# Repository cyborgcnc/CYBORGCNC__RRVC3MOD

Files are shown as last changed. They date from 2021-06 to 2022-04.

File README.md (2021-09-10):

# CYBORGCNC__RatRigVCORE3_MOD
Thse are modifications I recently made to the RatRig Vcore3 3D printer.  I drew a lot of inspiration from members of the Voron team, as well as other folks who have and are modifying this awesome printer.  I have also been a long time computer/gaming rig Modder, and I used some of the techniques there to make this printer simply awesome looking (my opinion). All parts were 3D printed, and the panels for all the sides etc., were cut from polycarbonate on my “homemade” CNC machine.  All of the modeling was done in Solidworks, and this would not have been possible, if it was not for the great models provided by the RatRig team!

I will be placing all the models I used to mod this printer here over time.  You can find me on the Facebook Group, so post there if you have any questions.

I would also like to thank Marcel Becker, Phil Brickwood, and Russel Brown, for their contributions in remixing some of these files for other sizes or part sizes.

If you like these mods, you can buy me a beer, or a cup of coffee!



<p align="center">
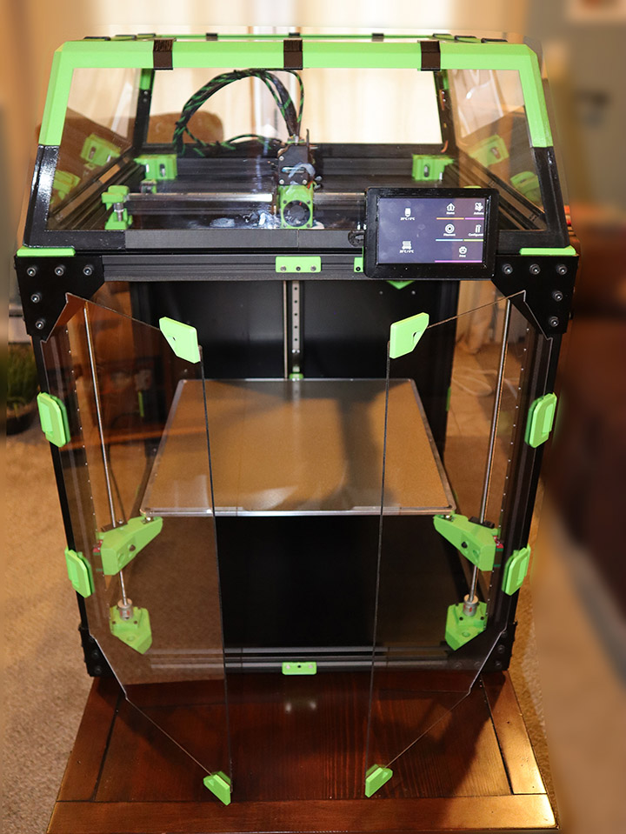
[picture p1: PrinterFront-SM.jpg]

</p>
<p align="center">
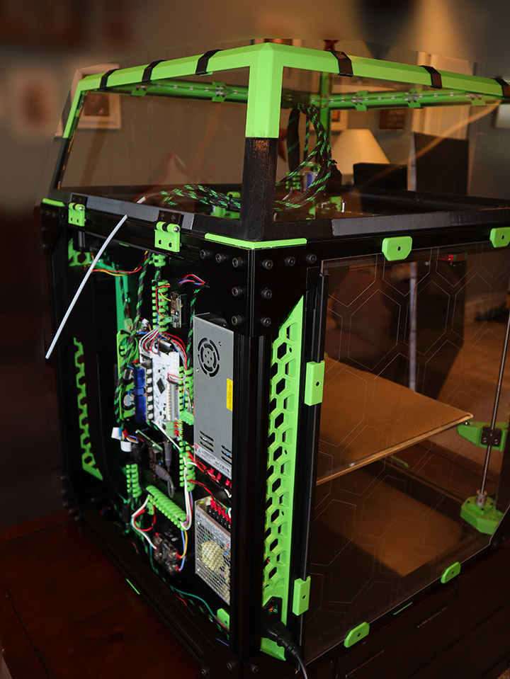
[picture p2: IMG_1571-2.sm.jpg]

</p>
<p align="center">
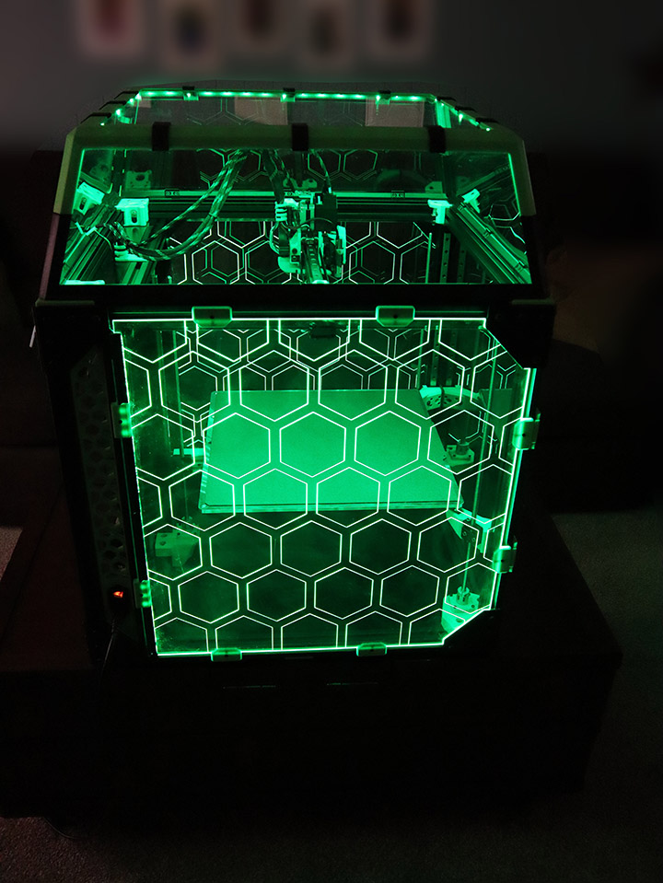
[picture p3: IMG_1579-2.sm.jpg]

</p>
<p align="center">
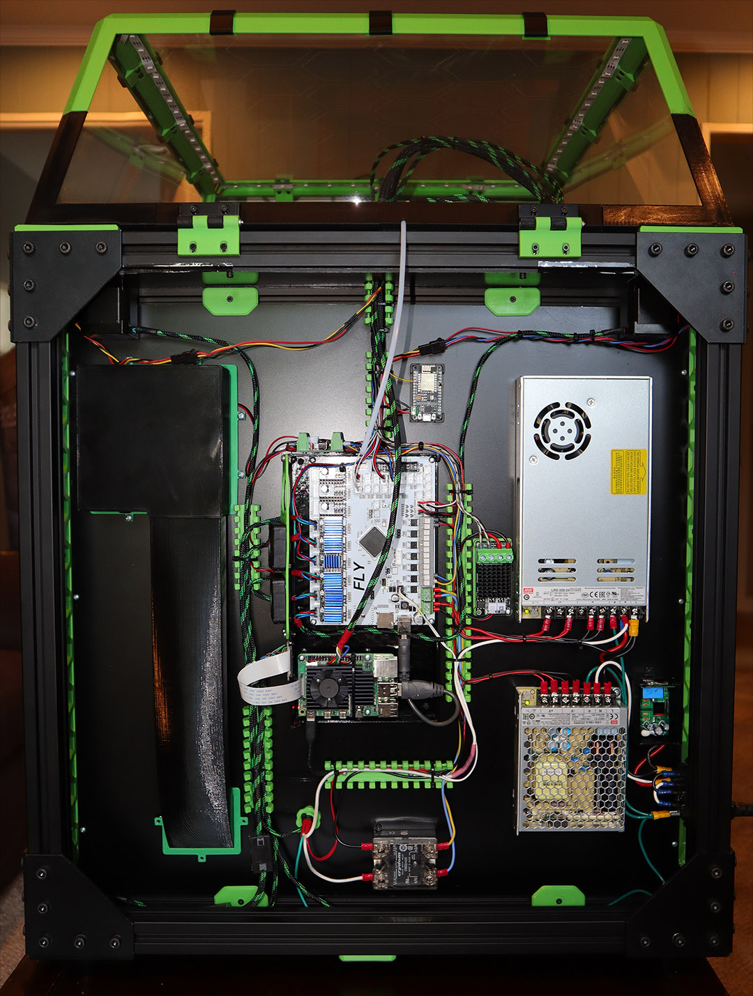
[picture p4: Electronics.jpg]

</p>
<p align="center">
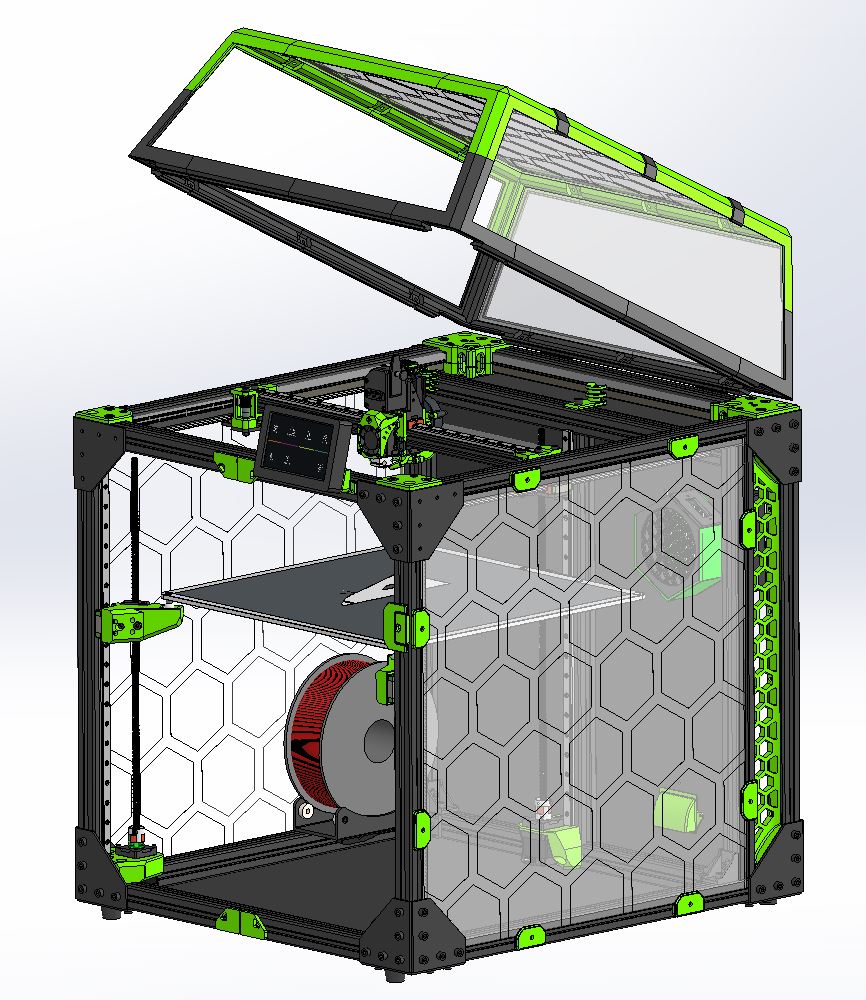
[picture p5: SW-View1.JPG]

</p>

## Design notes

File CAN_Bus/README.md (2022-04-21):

<h1 align="center">CAN Bus Modifications and Info</h1>

In this section I will detail the modifications I did to use a CAN bus tool Head for the Vcore3, and will also post the way I modified the EVA catridge to mount everything.  The product that I used, is the Mellow/FLY SHT42 board (https://www.aliexpress.com/item/1005004048980837.html).  They have two versions, I chose the SHT42, but both are pretty much identical in functionality.  I have included therr STEP files, so feel free to modify as needed, if you need to make changes to the way I mounted mine.

As you can see, since I am running an enclosed chamber, I tried to design a mount that will also incorporate a fan, so that I can cool the 2209 driver that is on the
tool head.  Mellow provides also ALL the connectors, as well as a heatsink, that gets mounted on top of the 2209.  I have to say, their quality is really good, and they 
did a good job on this board (time will tell for sure)

The pictures below, along with a couple of renderings, should be very self explanatory, as to how it all fits together.  I am using dual blowers for mine, and hence this is the way I modified the back plate of EVA.  You will need to remix or make other modifications if you are using a different setup.  At this point, I am NOT planning on modifying any other EVA mounts.  Also, I am running an Orbiter 2.0 (LDO) and everything was designed around that.  Any other extruder, and you might run into clearance issues....modify as needed.

I addition, you will also see, that I am using the UTOC-1 USB to CAN bus board from mellow.  This board basically plugs into the Rpi, and then gives a can0 port to the pi.  All communications on the CAN bus, then happen over this board.  If you only have ONE tool head, you can connect the SHT42 directly to the USB port, and then run a USB cable to the tool head (and separate 24V power).  Nothing wrong with doing this, and you will NOT need the UTOC board.  I have NOT tested this.  The only draw back to this, is you need to use a good shielded USB cable, and if in the future, lets us say, you need ANOTHER tool board, you will need to go back to CAN Bus and UTOC board.  I would strongly suggest you use 24V (and most use this) but your mileage will vary with 12v.  The SHT42 is rated to 9Amps total.  Plenty to run heaters and fans etc.  Again, POWER is POWER...do the math on what components you have and how much you need (the magic smoke will stay hidden).

You will need:

The boards from Mellow, a 25x7 24V fan, 4-m3x20, 2-M3x8, 2-M3x16 and 2-M3x10 Screws (or what ever you have around, to mount it all).  Again, look at the pictures below to see how it all fits together.  The fan mounts to the duct, and then there is a retainer for the top, which then mounts to the cover.  I tried to play around with different orientations, and this made the most sense.

YOU WILL NOTICE, that if you have a BLtouch, I extended the connectors for that to the side.  This was simply done, by soldering short cables, and then terminating them to a JST connector.  Again, the pictures below make this obvious.  I did this, because simply there would not have been a place to mount the fan, and keep all of it rather neat.  Feel feel to experiment, and share in case you come up with something different..what it is all about!!!

For the fans:  I have 4 fans total (blowers x2, hotend fan, and tool board fan).  The tool board has only TWO fan connectors...SO...I simply created a fan Y-Adapter, that basically runs the two 5015 blowers one port, and the hotend fan and tool board fan off the other.  This is pretty cool, since the 2209 fan turns on when the HE fan turns on, and then same when it turns off...worked out pretty darn good!  The SHT42 has a SEPERATE little MOSFET board, that runs the fans.  This is nice, since if this releases the magic smoke, you can simply replace it with another from mellow (you might want to order a couple to start with..they are like .90 cents!).

Wiring it all could not be simpler:

You connect the UTOC-1 to the USB board of the Rpi.  Then, you run the TWO Can lines, and 24V power to the toolboard.  You then connect all the fans/BLtouch/Endstops/Thermistor/Heater to the tool board.  4 Wires from your electronics to the extruder/tool head, can't beat that!  You will have to do the following to now make it all work:

-Make sure your Rpi recognizes the UTOC-1 board, and that it sees a can0 interface.  Read the Klipper docs on Canbus, that walk you through this.  Doing an "ifconfig -a" on the cli, should show you the port. (https://www.klipper3d.org/CANBUS.html)

-Now, follow the instructions on the Mellow/Fly site, to Flash the tool head with Klipper, and then use their example config, to modify your klipper config.  You are basically done. (https://mellow.klipper.cn/?spm=a2g0o.detail.1000023.73.7d0d62ce6fX67l#/board/fly_sht36_42/)

I am not going to go through a step by step install here, but find me on the FB group, and I would be more than glad to answer any questions....

HAPPY CAN-nibalizing!

<p align="left">
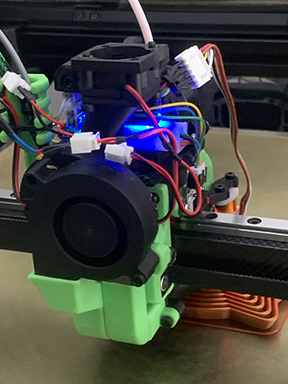
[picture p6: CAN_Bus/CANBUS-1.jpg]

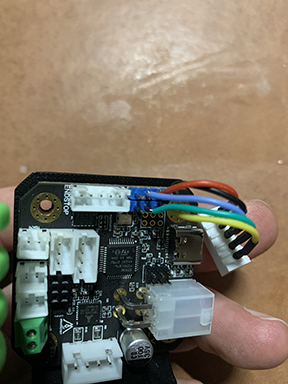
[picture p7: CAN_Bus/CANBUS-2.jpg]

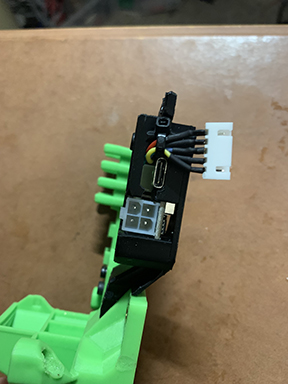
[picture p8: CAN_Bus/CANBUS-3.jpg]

</p>
<p align="center">
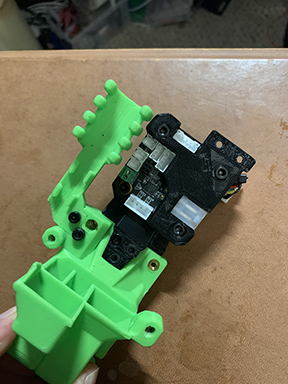
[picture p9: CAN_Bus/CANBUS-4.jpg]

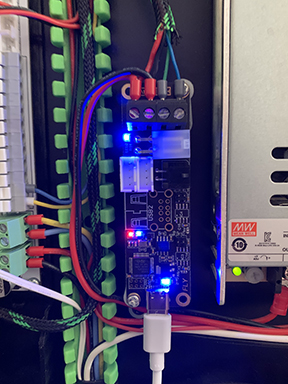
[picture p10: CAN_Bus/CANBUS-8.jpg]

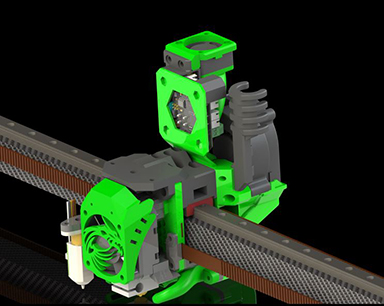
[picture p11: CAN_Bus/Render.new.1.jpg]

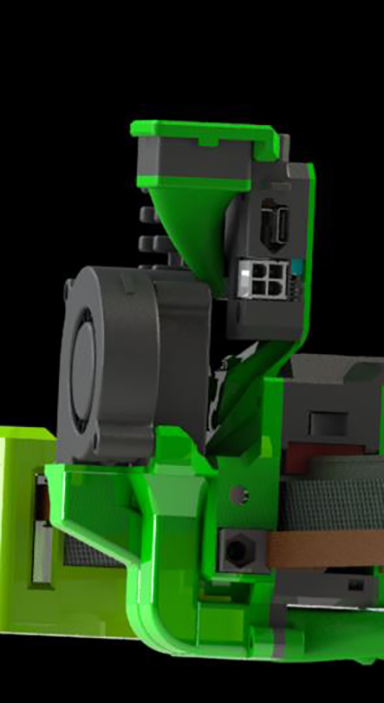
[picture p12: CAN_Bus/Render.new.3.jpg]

</p>

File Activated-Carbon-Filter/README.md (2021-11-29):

<h1 align="center">CARBON HEPA FILTER </h1>

I wanted to design a filter for my 400mm build (Jannik, has also remixed the Duct for a 300mm), that will allow me to print materials like ABS/ASA/PC etc. and be able to filter Particulate matter.
I did not want to design one that would vent the air to outside, as I wanted to keep all the hot air in the chamber, and this lead me to designing one
that is re-circulating the air.  For the most part, I think I achieved this, and so far, I have good results with this filter.

The filter uses a 120mm blower.  There was no sense in designing this with a regular radial fan, as pretty much any of those fans DO NOT have the
static pressure required to move air through a HEPA Filter, a pre-filter, and then Activated Carbon.  One can probably find such a fan, but it would more
than likely sound like a jet engine, at 24V volts.  The blower I am using is relatively quiet, and at 24V, it really pushes the air through with no issues.

The filter uses an "Activated Carbon Catridge" that gets installed inside the printer chamber, and with a bracket, this is fastened to the back electronics panel.
In turn, there is also a HEPA filter bracket and assembly, that houses the filter duct, and the 24V blower.  This gets mounted on the backside of the Electronics
panel.  You can see how all thesse components are installed in the pictures, and the whole thing is actually pretty straight forward and self-explanatory.

<p align="center">
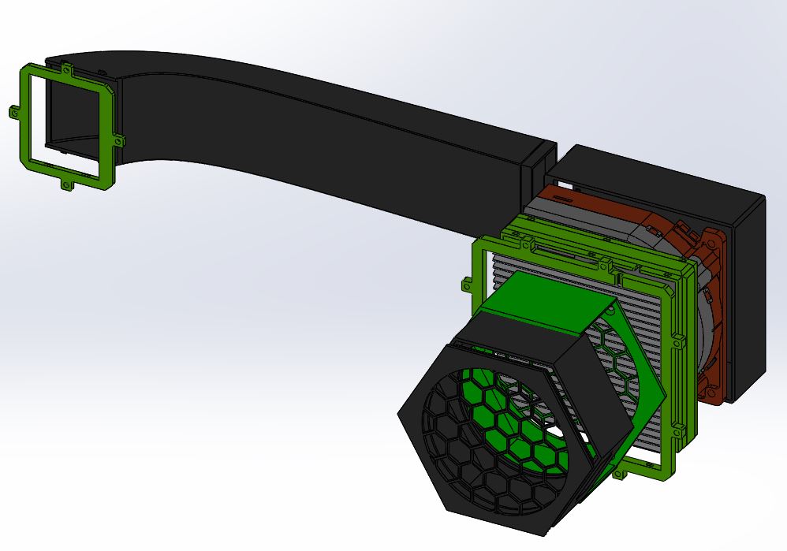
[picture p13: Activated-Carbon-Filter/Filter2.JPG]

</p>

The Activated Carbon can easily be purchased from a number of places.  The way the Catridge is assembled is, one has to use some fine mesh material.  I used
mesh that is normaly used for window screens, but really anything can be used, that allows the free movement of air.  This mesh material is glued and held in place by the retainer rings of the catridge.  As you can also see, the catridge has a square access hole at one of the sides, which is used to fill the catridge with Activated carbon.  You can then simply place a piece of tape over this to hold the carbon in place, and can easily be removed to replace the carbon.  Depending on the amount of printing you do, you will need to replace this every couple of months or so, but I have not done any extensive studies on the time frame (I welcome testing and suggestions).

The HEPA filter I used is one that is normally used for air purifiers, and this was cut to size, to fit inside the HEPA filter retainer, which then mounts to the 120mm Blower Housing.  Here are the links where I purchased most of these items described:

https://www.amazon.com/gp/product/B01KVX8RM8/ref=ppx_yo_dt_b_search_asin_image?ie=UTF8&psc=1

https://www.amazon.com/dp/B00GKVNI8E?psc=1&ref=ppx_yo2_dt_b_product_details

https://www.amazon.com/gp/product/B07V41X4RT/ref=ppx_yo_dt_b_search_asin_title?ie=UTF8&psc=1

<p align="center">
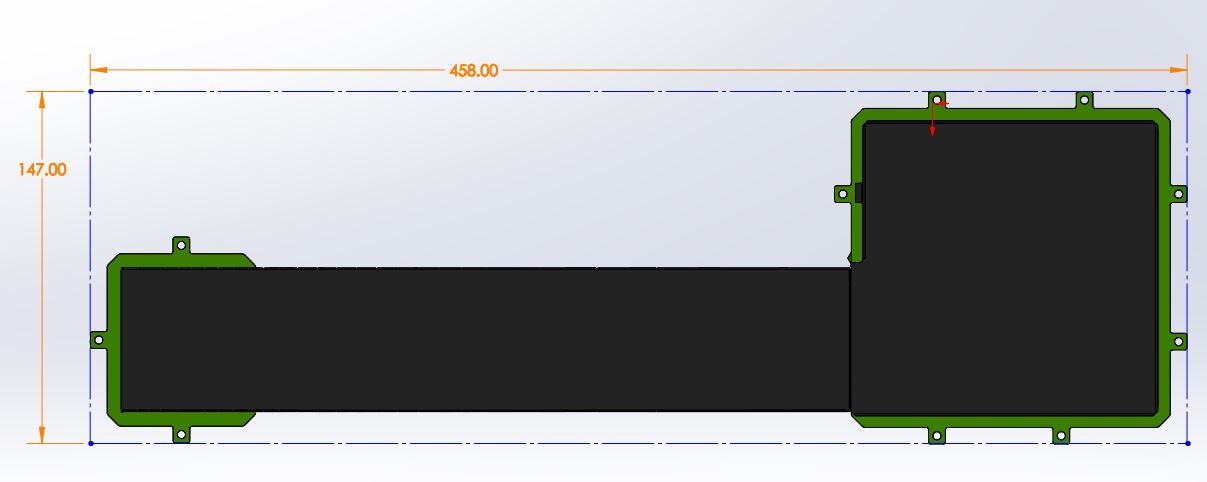
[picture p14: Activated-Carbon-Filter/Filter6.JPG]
  
  </p>
  <p align="center">
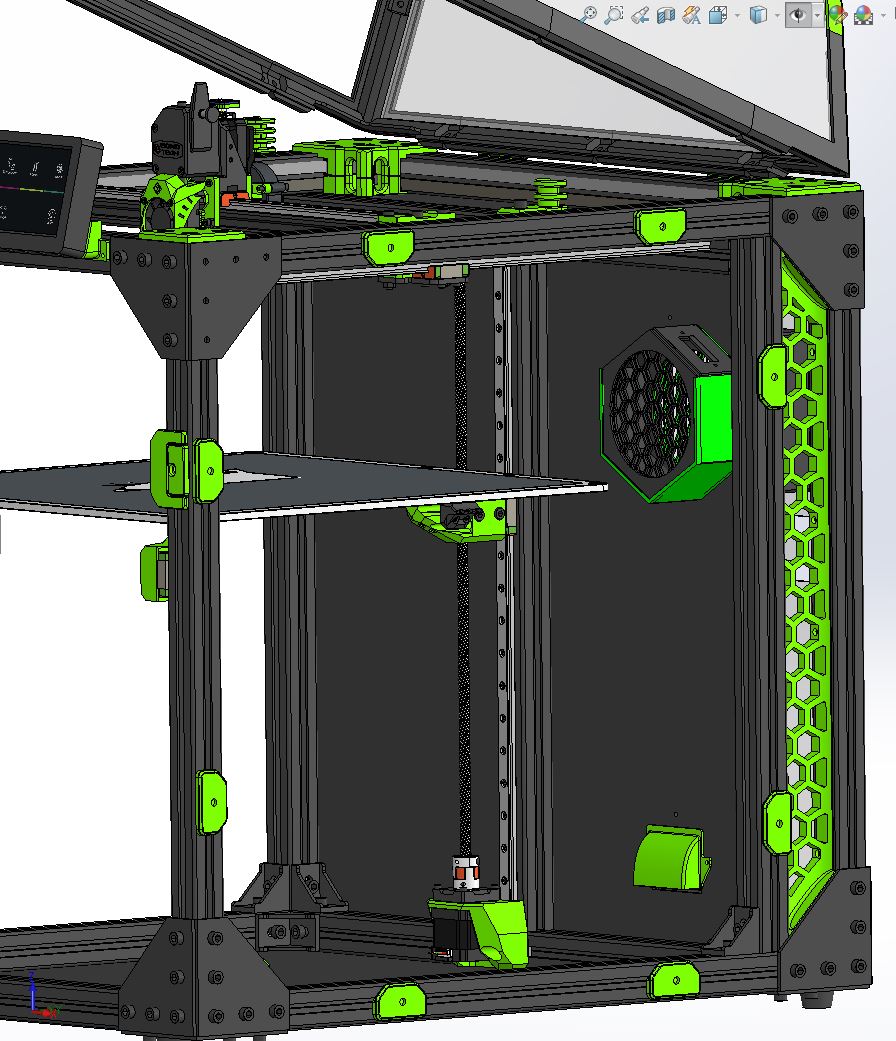
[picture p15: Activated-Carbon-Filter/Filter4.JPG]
  
  </p>
  <p align="center">
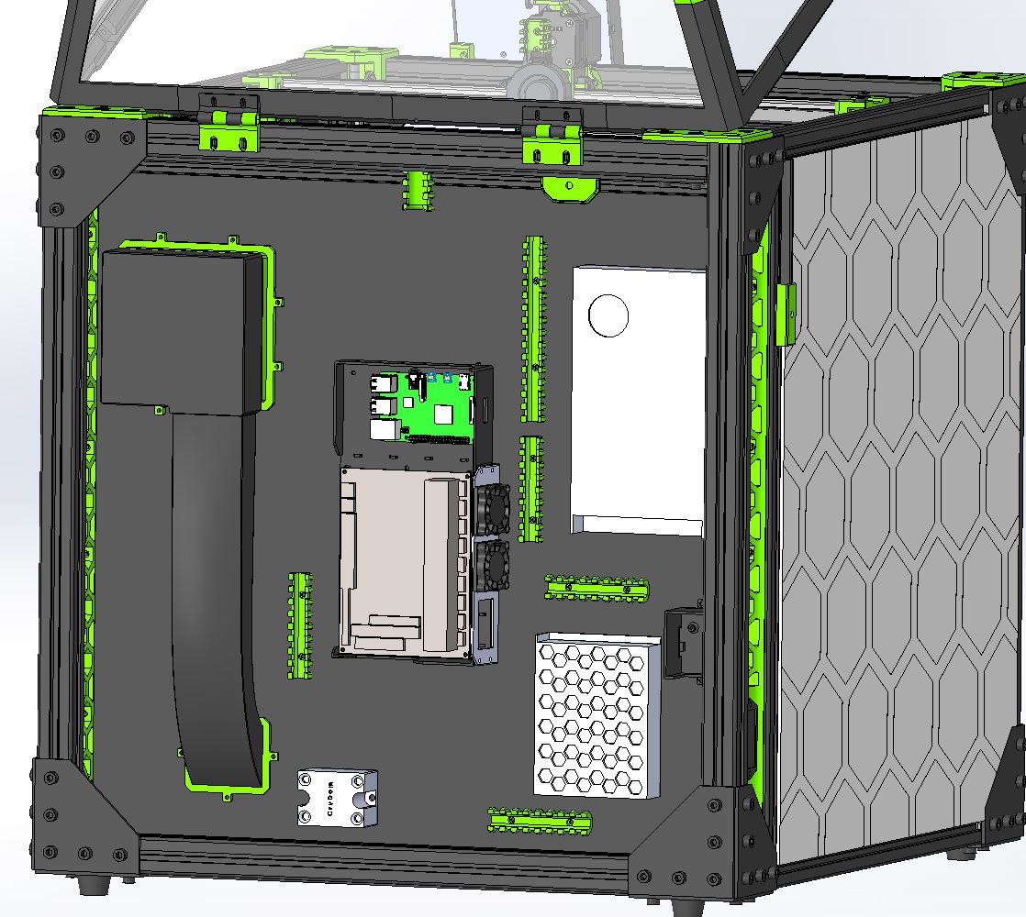
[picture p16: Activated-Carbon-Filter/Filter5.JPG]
  
  </p>
  
  This Filter will fit the 300mm and 500mm version of the printer HOWEVER the long "recirculating" Duct, would have to be made longer or shorter.  I have provided the STEP files, for you to remix in your favorite CAD package!
  
  <p align="center">
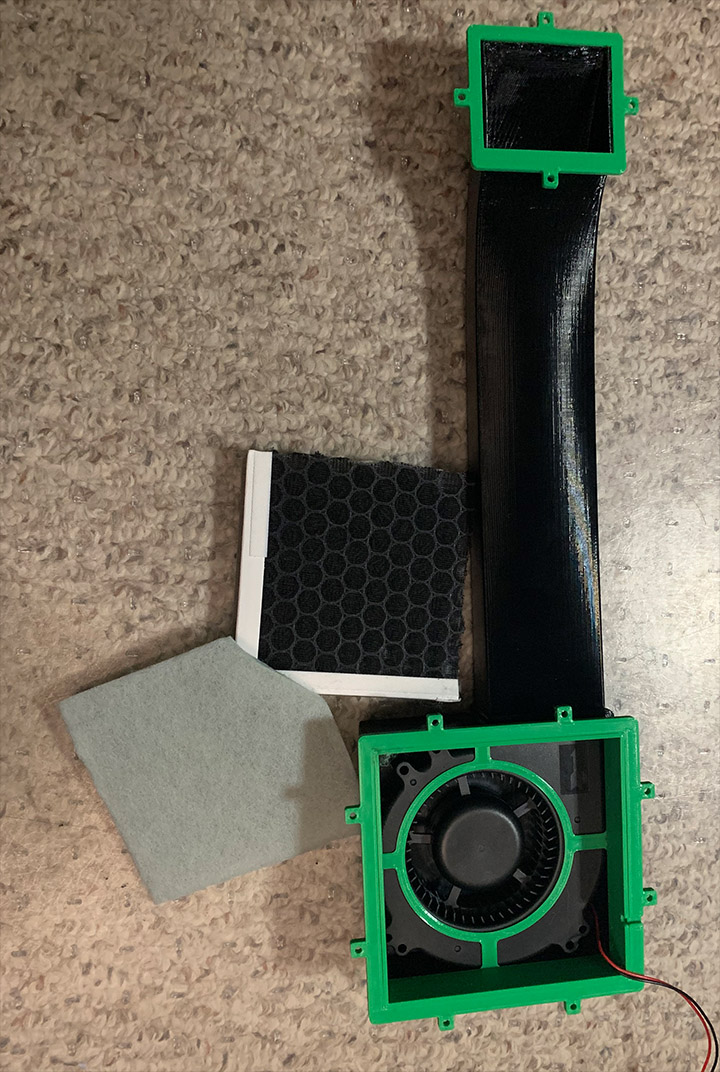
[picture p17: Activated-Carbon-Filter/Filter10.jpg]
  
  </p>
  <p align="center">
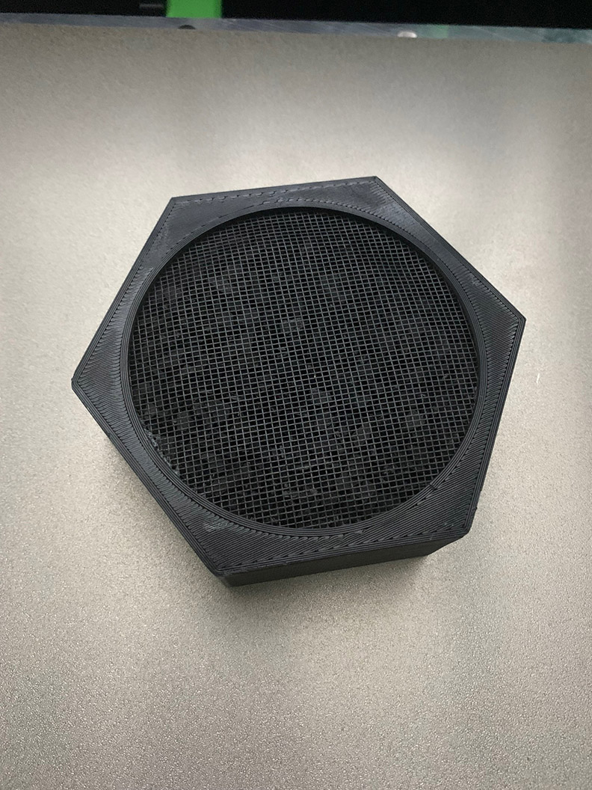
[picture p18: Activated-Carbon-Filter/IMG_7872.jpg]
  
  </p>
  <p align="center">
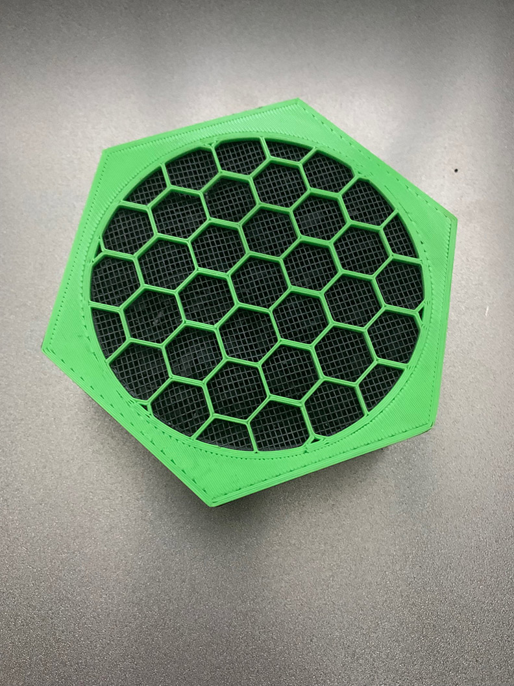
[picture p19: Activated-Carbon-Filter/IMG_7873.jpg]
  
  </p>
  
   <p align="center">
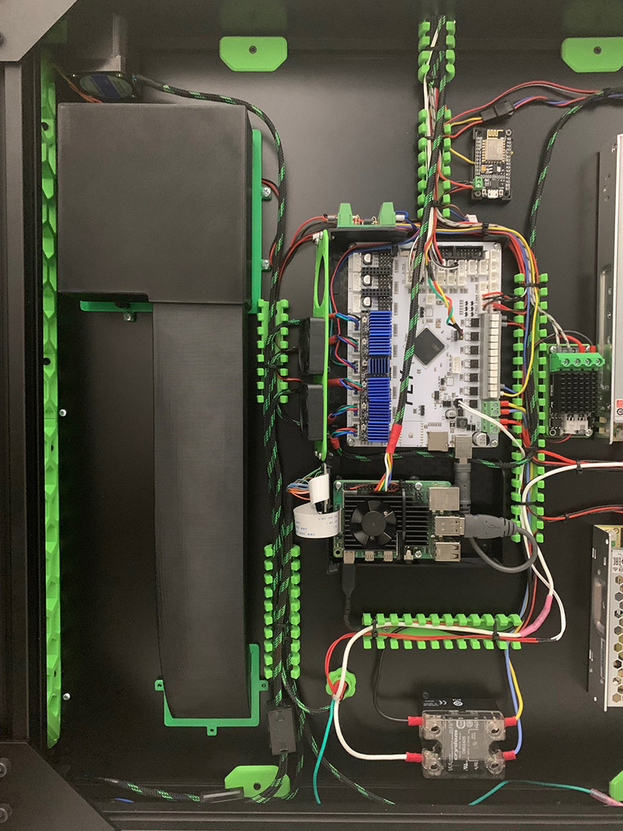
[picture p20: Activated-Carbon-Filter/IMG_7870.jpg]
  
  </p>
  <p align="center">
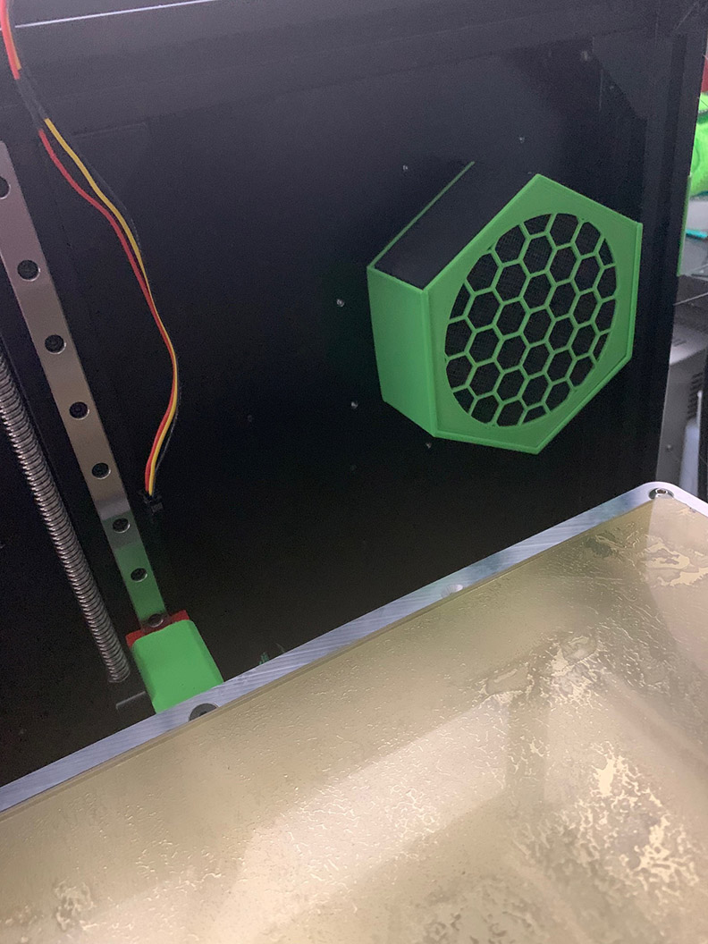
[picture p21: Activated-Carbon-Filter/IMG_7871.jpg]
  
  </p>

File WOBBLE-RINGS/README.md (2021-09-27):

# WOBBLE RINGS FOR VCORE3 PRINTERS

As you can see from the work here, I have created a set of “wobble rings” for the arms of the Vcore3.  This idea was originally posted by MirageC for his Hevort build.  
On his youtube video, he explains how he is able to source some very cheap ball screws, and make them better through the use of a system that allows them to 
freely move (if not dead straight).  As such, it eliminates print artifacts.  I thought this would be a good idea to use for the Vcore, and the leadscrews it uses. 
Ultimately, I would be looking for a belt driven Z, but at the moment, and due to the weight of the table, I put on the back burner.

Reason why I did this, was because I was getting small artifacts on my prints, and they were all measuring exactly 4mm apart, which pointed to screw wobble.
This is NOT to say you will have this problem!  In fact, the Vcore3 design is one that should ELIMINATE any sort of wobble, but if it shows up, it shows up.
Here is my fix here.

What you will need:

-You will have to print the Back-Arm, and then the Front Arms.  Bear in mind, that the Front arms are simply mirrors of each other.  
 So place the right one say in your slicer, mirror it, and you will have the left one.
 
-You will need to print the Rings.  These are comprised of Top Rings (you need three), Middle Rings (you need three) and Bottom Rings (you need three).

-Neodymium Magnets: 8mmx5mm (you will need 12)

-Steel pins: 8mmx3mm (for the disks, you will need 48..I sourced these from McMaster Carr)

-Steel Pins: 3mmx35 (you can use the original ones that came with the kit).  These are for the arms, and where the ball end of the table rests ^ of them).

-Magnets for the Arms: Use the ones that came with the printer, in the original arms.

-TR8x4 Nut (can be anti-backlash if you want..3, one for each ball screw))

-Heat Inserts (To attach to the Arms, which is used for attaching the TOP Rings to the Arms). I used 4x5.5 M3..so the SHORT M3 Heat Inserts.

-4mm Steel Balls...you will need 12 (sourced from Amazon)

-3mm Screws, for attaching the top Ring, and the Arms to the Linear Bearings

-20x8mm Bearing for the front and Back support Brackets (Top bearings to support the lead screws and keep them from whipping)

The way you put these together is pretty self explanatory.

Just look at the pictures, and you will be able to see how they go together.  Basically, the Steel Balls sit between each of the Steel Pins in the disks, and they are held in place by the magnets on the other side.
PAY ATTENTION: to mount that magnets in a way that they ATTRACT each other, and NOT repel!

NOTE ON BACKLASH:  Since the steel balls sit between the steel pins this does two things.  It prevents any backlash, but in even more importantly, it allows the screw to spin, without the friction in the screw pushing the rings out of alignment.  What makes this possible is obviously the steel pins and balls, but also the WEIGHT of the table!  Even at a pretty fast Z axis homing routine, I never had an issue where the rings would go out of alignment.

ON SCREW ALIGNMENT:  Your lead screws would still need to be aligned with the rail and the stepper shaft!  These rings DO NOT change this requirement.  Reason for this is, that IF the screws are not aligned, and now they are free to move more, as the stepper turns, there is the potential of the screws whipping around!  This would cause them to wobble a lot, causing a lot of noise, and not a situation you want to be in.  A future improvement to this system would be to create a small bracket that would go over the linear rail on the top of each screw.  EDIT: I HAVE DESIGNED THIS BARCKET, and you can download it from ther files above.  The front is a mirror of each other, so print one, and then print a mirror for the left and right front led screws).  In this bracket, we would then fit a bearing, which would restrain (in a lose manner) the screw at the top.  This would allow one to have the screws not perfectly aligned, but still retain all the benefits of this system.  I am in the process of designing these brackets, and I will post them here as well shortly. EDIT: These are now posted here, labeled as Bed-Screw ALign brackets.

<p align="center">
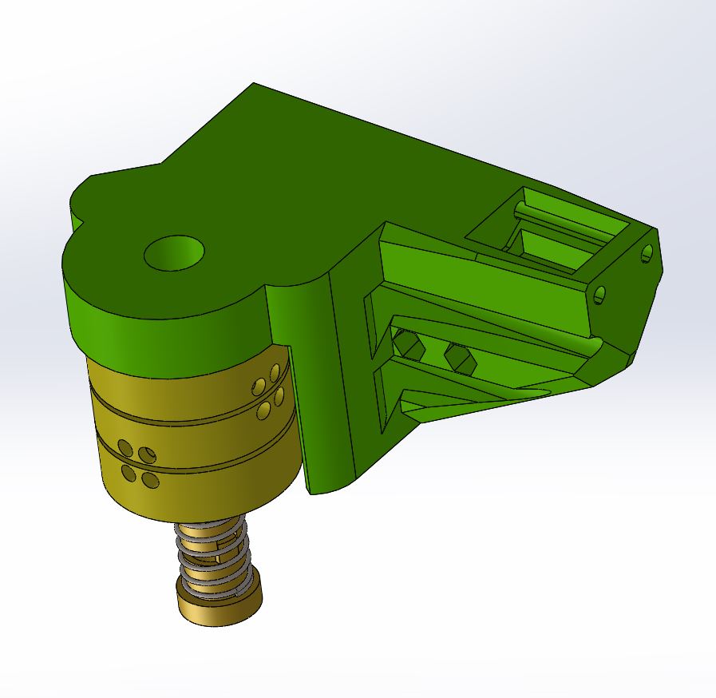
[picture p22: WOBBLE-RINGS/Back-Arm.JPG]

</p>
<p align="center">
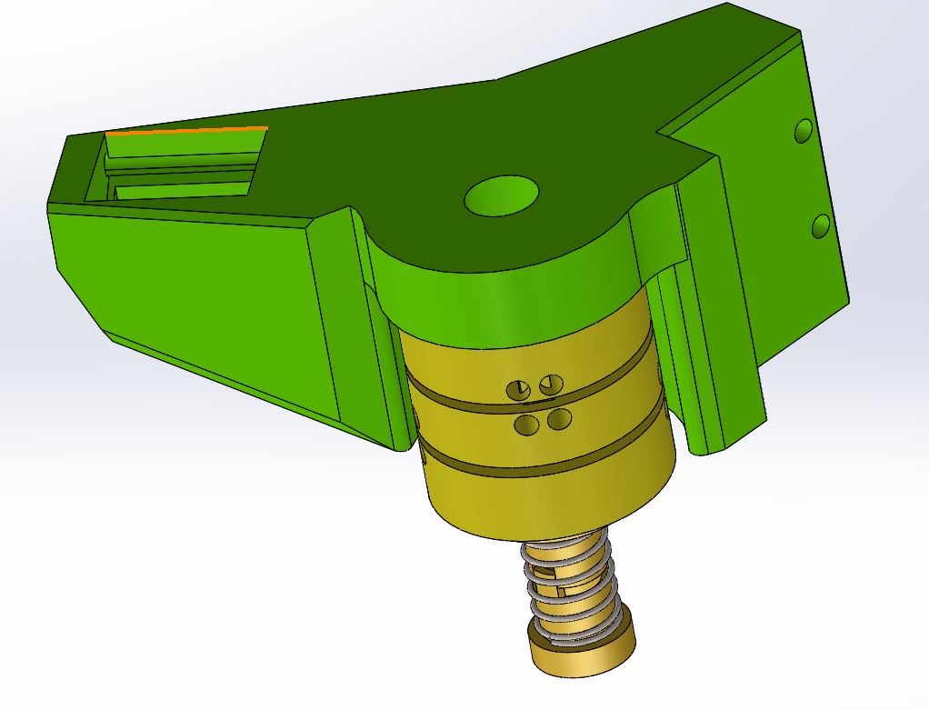
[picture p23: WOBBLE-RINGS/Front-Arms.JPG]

</p>
<p align="center">
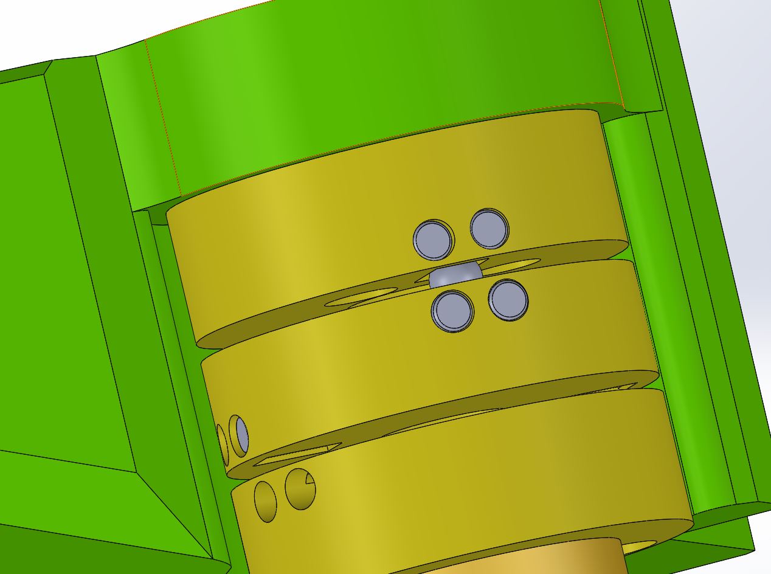
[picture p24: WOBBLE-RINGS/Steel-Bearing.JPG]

</p>
<p align="center">
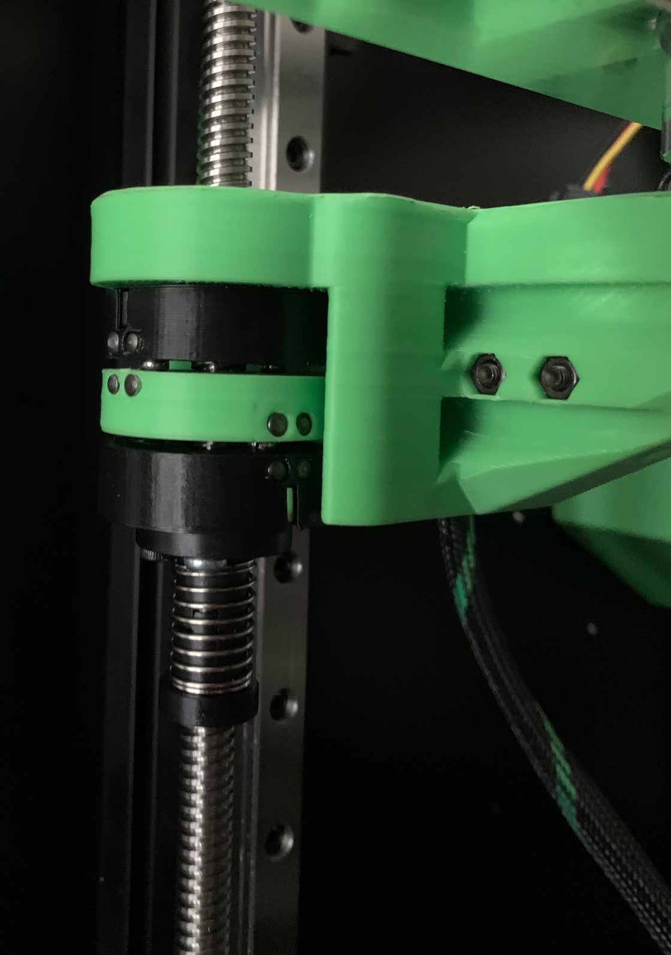
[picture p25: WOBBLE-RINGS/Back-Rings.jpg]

</p>
<p align="center">
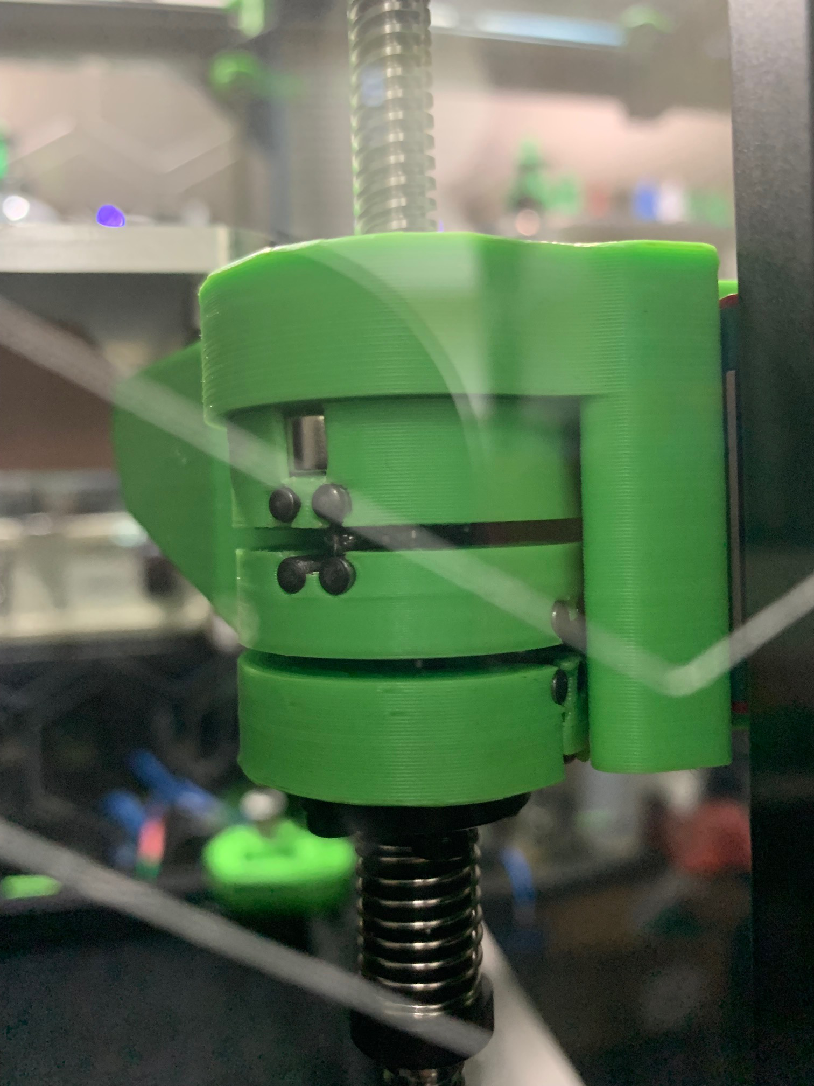
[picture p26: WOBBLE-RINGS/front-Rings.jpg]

</p>
<p align="center">
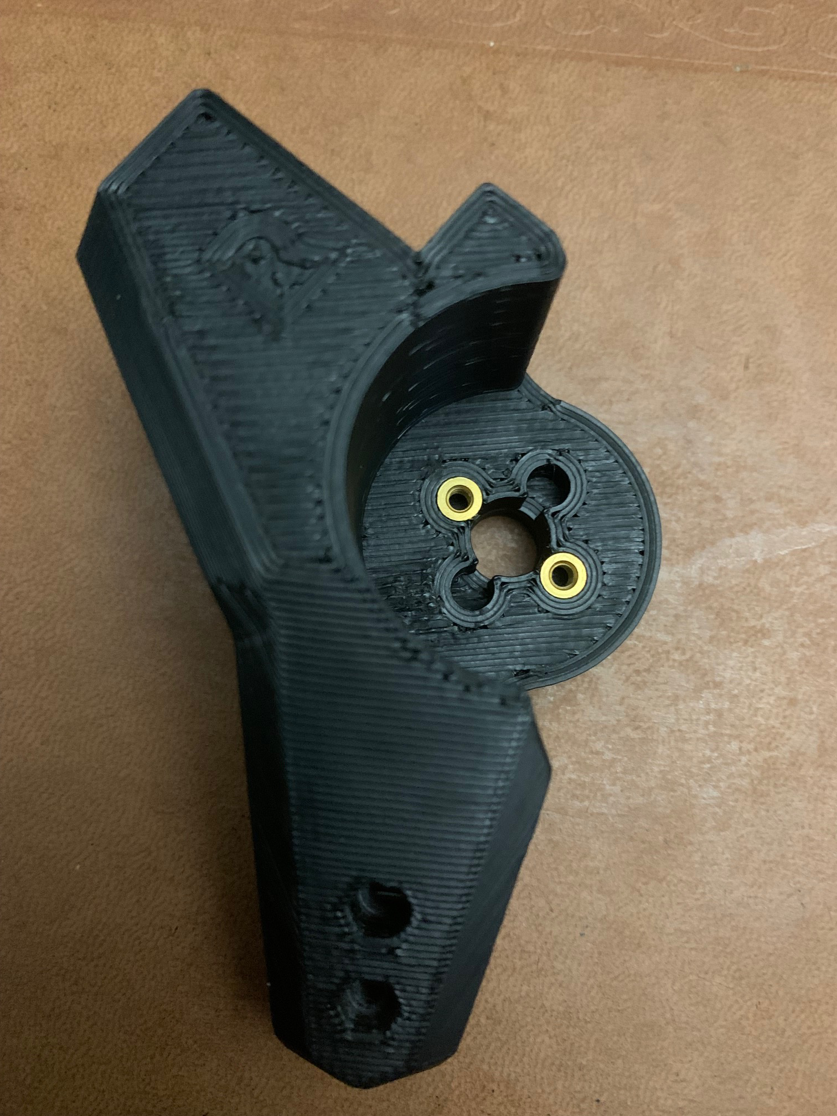
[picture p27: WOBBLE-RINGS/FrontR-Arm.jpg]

</p>
</p>
<p align="center">
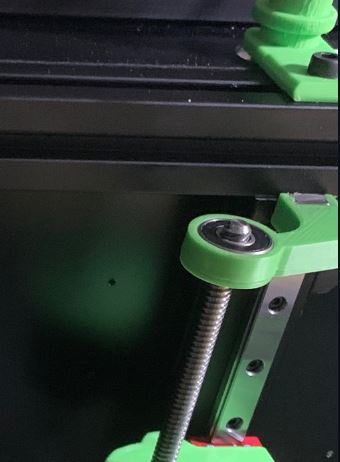
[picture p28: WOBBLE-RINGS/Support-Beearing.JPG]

</p>

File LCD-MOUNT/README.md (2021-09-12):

# LCD MOUNT

This is the case and mount I used for my LCD, to mount in front of the printer.

The case is made to fit the BTT Pi TFT50 LCD display.

As this is a display that is meant to connect directly to the pi, over the DSI coonector, I used a breakout DSI circuit board, which allowed
me to run cables through the printer frame (I used Cat 6), and then another breakout board to connect to the pi in the back of my printer.
You can see some of the photos I have posted.

As such, this you might need to remix, depending on the screen, on on the way you will connect your screen.  I designed this specifically for my purpose,
but I have included the .step files, which you can easily bring into any CAD package, and remix as needed.  I might redesing this at some point in time,
as I would make the mounting a little easier, but the mount works for me, so it is not per say broken that needs fixing... :-)

I have also included the mounting clips/brackets, I have used to mount to the front 3030 extrusions.  Print one and another in mirror mode, for the 
left and right.  Again, modify as needed.

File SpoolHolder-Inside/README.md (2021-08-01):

# INSIDE PRINTER SPOOL HOLDER

This is my take on placing the spool inside the printer.  My chamber with a 105C on the bed, get to about 55-57 C…..perfect for drying out filament!  So having the spool inside the printer while printing is a good thing!  In addition, this design allows you to print a couple of these brackets, and you can have OTHER spools drying inside your printer, while you are using one to print from.

You will need a 16mmx6 bearing (4 of them,), and some hardware to attach them to the holder, pretty self-explanatory (look at the pictures, and you will see how this is put together.

The original spool design, even though good, would be very prone to tangling of the filament, especially on a spool that is new.  As it would rotate, the inertia of the initial movement would cause the spool to rotate in the opposite direction, causing the filament to unwind, and then tangle around the holder.  This is especially true if there is no filament guide.  With this design, I have eliminated this, since as you can see, the spool is supported in the bottom by the bearing and the sides of the holder.  If it back rotates, the filament cannot go to the sides, and this should eliminate the tangle….at least this has been my findings so far after using this holder for a couple of prints.  Would love to hear your results if you use this, so that if there is any modification required, we can do that. You can also mount this bracket to the back of the printer, as there is also clearance there.  It is meant for a 1KG spool, around 200mmx67 or so..standard size.  Anything bigger it will not fit, but all up to you to modify or remix as needed, as I have provided the source files.  The bed will NOT interfere with the spool, as there is enough clearance, and the holder sits BELOW the bed, when the bed is all the way down....so no issues (tested this on a 400mm Vcore3, others should be similar, let me know).  I printed in ABS, .3layer height, 3 walls, 25% infil....I printed it VERTICALLY, and no supports needed of any kind.

You can use PTFE tubbing to guide the filament to the top of the printer, and for this I created some clips that you can print and use as required.  I would recommend a 3mm inside diameter for your PTFE tube, since most are running a direct drive extruder.  This will give you a “Reverse Bowden” configuration, with very little friction, and very good results.  You can see one of the pictures here how I mounted mine.  You can vary this as needed.

Start Printing and Drying!! :-)

<p align="center">
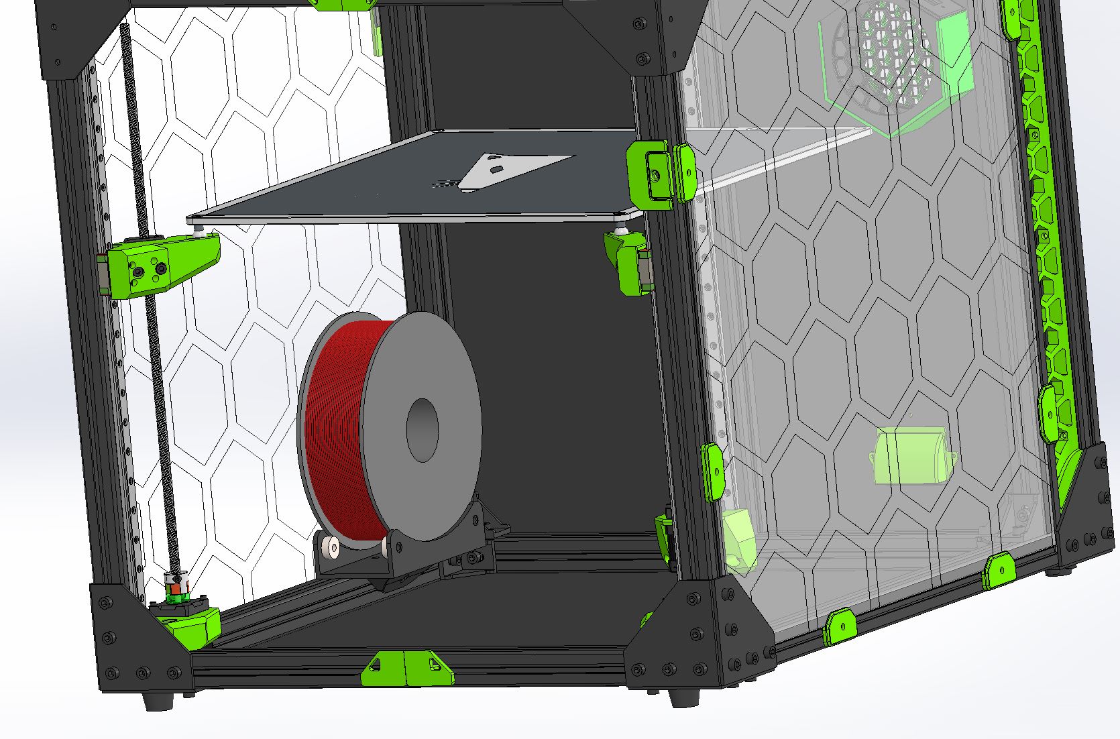
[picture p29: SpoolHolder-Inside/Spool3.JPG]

</p>

<p align="center">

</p>

<p align="center">

</p>

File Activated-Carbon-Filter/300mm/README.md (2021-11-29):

This is a Remix of the Carbon Filter Duct, thank to the awesome work of Jannik!

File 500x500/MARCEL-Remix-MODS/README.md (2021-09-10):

# MARCEL BECKER TOP LID FILES FOR VCORE3 500mm

Thanks to the GREAT WORK of Marcel Becker, we now have the panel sides, and the Top Lid for the 500mm Vcore3.  As you can see, Marcel did an absolute AWESOME job in remixing my 400mm design for the 500, and I have to say his color scheme is drop dead gorgeous!  As you can also see, he remixed the front doors, adding some really good looking handles to them!  Honored to be hosting these files here for sure!

Marcel is on our FB group, and if you guys have any questions, I am sure he will be more than glad to answer them.  He is currently working on building this printer, at which point, he will also post some more pictures of this awesome build!

THANK YOU Marcel for the awesome work!!

<p align="center">

</p>
<p align="center">

</p>

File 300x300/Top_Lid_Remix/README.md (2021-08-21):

# 300mm Top Lid Remix by Phil Brickwood

This is a top lid remix very generously done by Phil Brickwood, for the 300x300mm model.  Phil will post more pictures when he receives his printer, and I am sure
any adjustments if needed.

You can reach him on the FB group of you have any questions.  Thanks for the contribution Phil!

<p align="center">

</p>

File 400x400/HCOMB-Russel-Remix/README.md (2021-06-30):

# Russel Brown Mod

Russel has produced (Thank you!) a version of my HoneyComb sides to accomodate the RatRig rj45 Adaptor.

Modified honeycomb back panels for the Standard Ratrig RJ45 connector
and push-fit IEC fused inlets all based on Spiro Argyros's most
excellent work found here:

https://github.com/cyborgcnc/CYBORGCNC__RRVC3MOD

The STL files are half panels and should match up with the top half STL
files in Spiro's github.  The STEP files are full length for those with
large enough print beds.

The printed RJ45 'keystone' socket holder is here:

https://github.com/Rat-Rig/V-core-3/blob/main/cad/printed_parts/extra/stl/lan_socket_adapter.stl

and bolts to this back panel with M3x16 screws.

I couldn't find the IEC connector used by Spiro so I used a push fit one
which seem more freely available. I got mine from here:

https://www.ebay.co.uk/itm/193566579018?var=493785159538

The push fit IEC connector requires a notional 47x27mm cutout and
notches for the retaining clips.  In reality, I found it was slightly
oversize so the cutout allows for this.

While these parts are notionally labeled as 'Left' one can, of course,
simply mirror them in your slicer if you want to use them on the right
hand side.

<p align="center">

</p>
<p align="center">

</p>
<p align="center">

</p>
<p align="center">

</p>

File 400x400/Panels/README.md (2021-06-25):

# PANELS
Here you will find the side, front door, and bottom panels I created for the printer.  The back panel, is Aluminum Composite material.  This is commonly referred to as ACM panel material, and it is thin aluminum, on both sides, with some sort of plastic in the middle.  The reason why I chose this for the back, is because aluminum can act as a good heatsink, but also, it is VERY easy to work with, especially for mounting.  Simple machine screws are all that are needed to be able to mount electronics, power supply, etc etc,  Obviously, since aluminum is conductive, you must take care as to how you mount these, and the pictures of my machine, can show you how I mounted mine.  You will also notice, that there are holes cut for the Carbon/HEPA filter I designed.  You can remix this if you want, and leave the holes out, but that is why they are there.  Anyway, pretty straight forward, and if you have any questions, just ask.  The bottom panel is also ACM.

The side panels are polycarbonate.  As you can see, I have also included the STEP file, since I decided to engrave these on my CNC machine with a hexagonal type of pattern.  I then created LED mounting "clips" that allowed me to use Mini-NeoPixel LEDs to light this panel from the side.  The effect of this is quite awesome, as it looks like neon, highlighting the hexagonal engraving.  Obviously you can engrave anything you want, and the effects can be dramatic, especialyl if you couple them with printing status type of functionality etc.

The front door (panels are identical) is again pretty straight forward, and this is mounted with the hinges and clips I have provide here as well.  Look at the pictures again, and it is easy to determine how these are mounted.  

The tollerance of these are TIGHT!  This is by design, since I wanted to make sure as much heat as possible is kept in the printing chamber.  This was also aided by using thin 1mm weather strip to line the ooutside of the panels.

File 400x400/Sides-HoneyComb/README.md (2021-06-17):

# HoneyComb Sides for Electronics

As you can see, these are the sides I designed for placing on the sides of the electronics area.  These are for the 400mm Printer! (I might remix these later for other sizes,
but for now, 400mm it is).

Pretty self explanatory as to how you mount them.  I have SPLIT UP the files, so that you can print them on a reasonably sized printer.  All you need is some 3mm screws, and
3mm 30x30 T-nuts to mount them.

The Left side, is made to accept an AC/Fuse combination plug, like the one you can find on Amazon.  I printed in ABS, flat side down, NO SUPPORTS needed...3 top/btm layers and 4 walls...



<p align="center">

</p>
<p align="center">

</p>





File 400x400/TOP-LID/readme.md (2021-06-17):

# TOP LID FILES

Here is where you can find all the files that can be printed to construct the top lid.  The parts will require 3mm screws as well as heat inserts (M3-.05 SHORT).
This will make the assembly of the top lid very easy, with no glue required, as all parts are MECHANICALLY attached.  In addition, I have made the top lid able to
be sealed with common weather strip, and the size of this should be 5mm wide and 1mm thick (you can find it on amazon).

Go also into the images directory, and download the images I uploaded of this lid, so you can get a better idea, as to how I put it together.

In addition to all this, the top part of the lid, has been designed to be able to also accept NeoPixel LEDs, and these can easily be attached around the inside of the
top rim, and wired as required.

All of my parts where printed out of ABS, and the panels for the lid sides, are polycarbonate (3mm thick) ( so it will handle heat well).  You can change this to any material you want.

<p align="center">

</p>

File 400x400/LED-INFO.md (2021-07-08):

# LED INFORMATION and Details

The LEDs I used to light the side panels, are know as mini-skinny-neopixel LEDs.  They are available from adafruit, and here is the link where you can find them:

https://www.adafruit.com/product/2964?length=1

These are very easy to implement for lighting panels from the side, especially engraved panels.  Engraved panels when lit from the side, produce a neon like effect, which is really cool.  You can tie this with printer events.  The possibilities are endless.  There are many way to achieve this, and it all depends on the firmware you will choose for your printer.  Klipper has support, as well as others.  Another way to do this (and the way I am doing it) is to use an external controller to control the RGB LEDs and then through a plugin, tie them to printer events.  Octoprint supports the WLED project, which is one of the coolest way to control the LEDs, with an ESP8266 board (which again, is what I am using).  More reading for you here:

https://github.com/Aircoookie/WLED

https://plugins.octoprint.org/plugins/wled/

Yes, I am using Octoprint, and until Fluidd or mainsail come close to the functionality, it is what I will be using.  I have had no issues with my printer, or stuttering, or any of the other nonsense you read online.  It works, and it works great!

The clips I am using, I am simply attaching to the side-panels with double-sided tape, such as 3M, or really any other brand you like.  I have provided the STEP files, so you can shorten, or lengthen this model to your liking, and to your panel, in your favorite CAD package.  For me to provide every flavor, for every printer is not going to happen.

ENJOY!

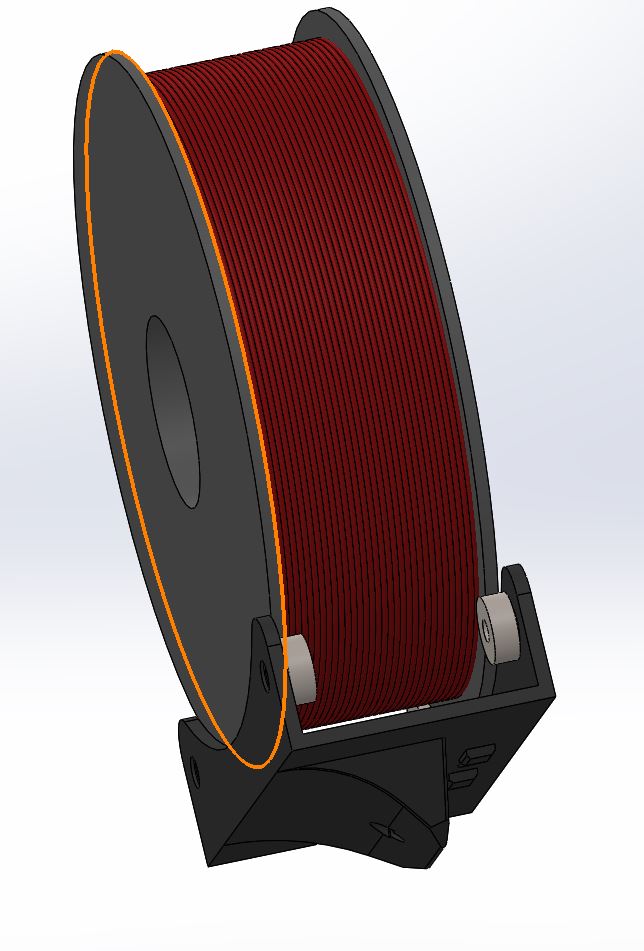
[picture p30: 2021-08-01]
SpoolHolder-Inside/Spool1.JPG

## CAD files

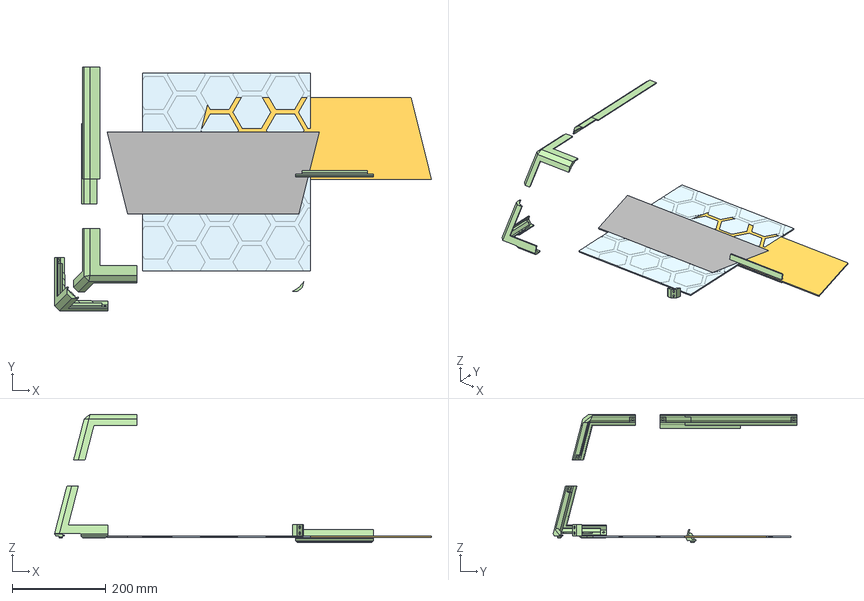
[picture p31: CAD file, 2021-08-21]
300x300/Top_Lid_Remix/Top-Lid-V3.Assembly-parts.step
805.0 x 520.7 x 273.9 mm

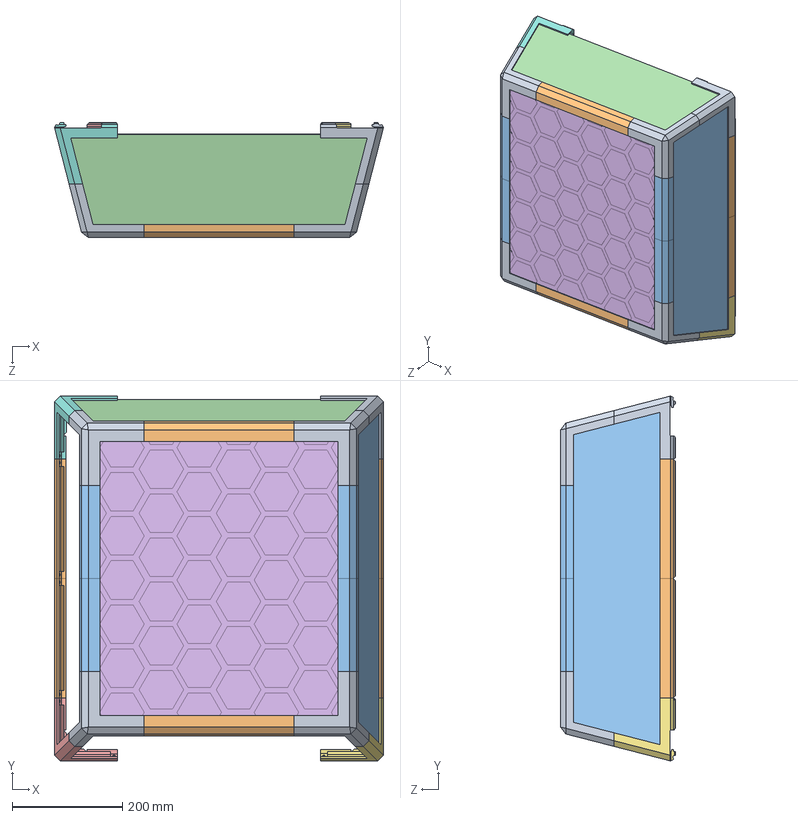
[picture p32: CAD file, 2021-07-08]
400x400/TOP-LID/STEP-FILES/Top-Lid-V3.Assembly.STEP
596.8 x 661.8 x 208.6 mm
Top-Corner.V6.20mm.V2 x 4
Top-Bar-274mm x 2
Top-Bar-339mm.HALF x 4
TOP-Clips-Joiners
Btm-left-Corner.V6.20mm
Plexi-Top-Cover
Btm-RIGHT-Corner.V6.20mm
Btm-Back-LEFT-Corner.V6.20mm
Btm-Back-RIGHT-Corner.V6.20mm
Btm-Bar-SIDES.HALF x 4
Lid-Side-Panel-SIDES
Lid-Side-Panel-FRONT

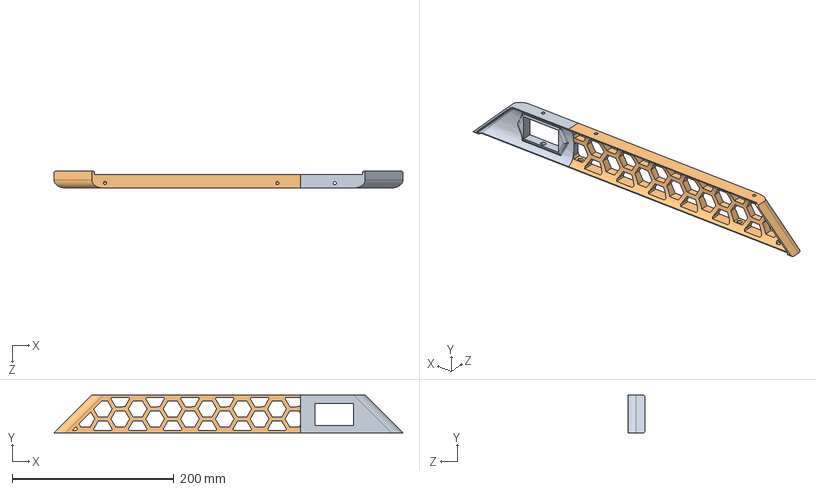
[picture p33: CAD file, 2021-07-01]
300x300/HCOMB-SIDES/HCOMB-LEFT.300mm.STEP
431.7 x 46.8 x 21.0 mm

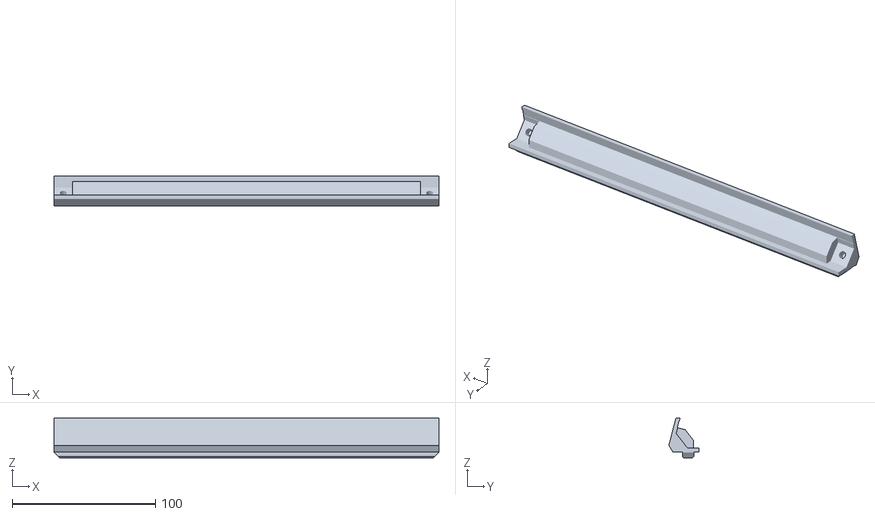
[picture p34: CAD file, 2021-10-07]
300x300/Top_Lid_Remix/Lid_Bottom_Center_v2_300x300.stl
268.6 x 21.2 x 27.9

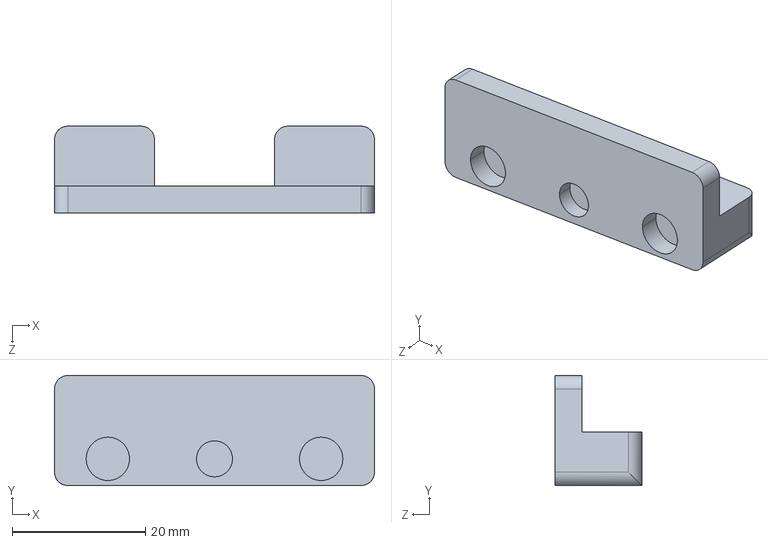
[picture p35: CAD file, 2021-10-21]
400x400/Door-Hinge-Plate.STEP
48.0 x 16.5 x 13.0 mm

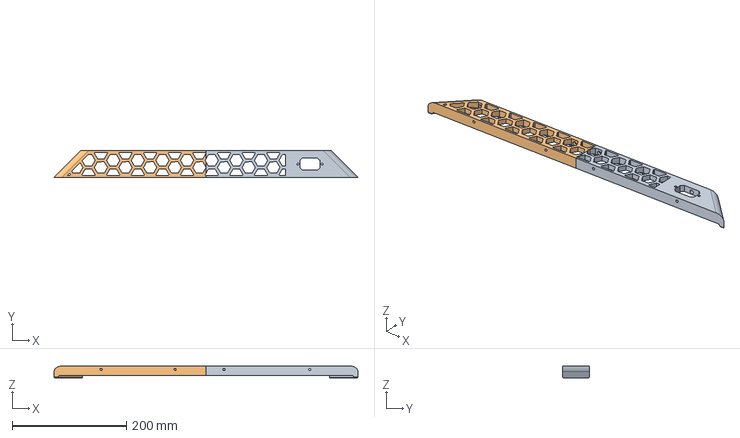
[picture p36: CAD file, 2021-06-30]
400x400/HCOMB-Russel-Remix/Back-Hcomb-Left-Half2-RJ45.step
531.7 x 46.8 x 21.0 mm

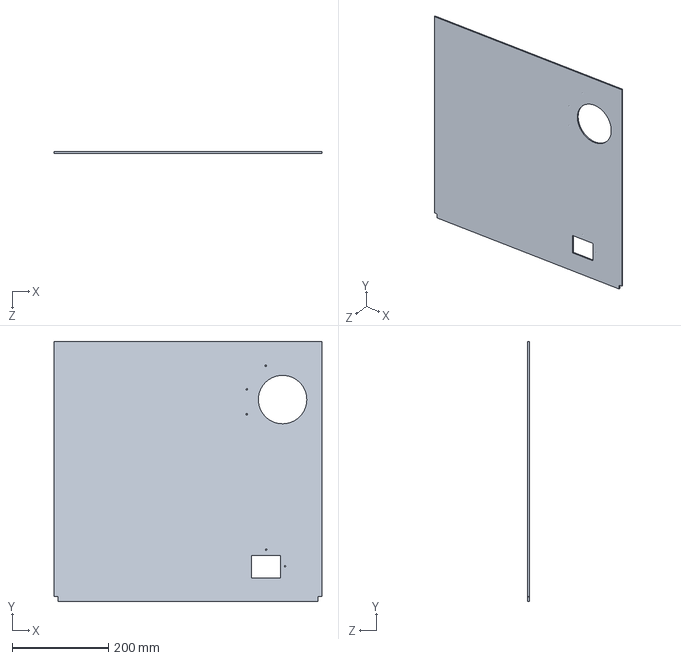
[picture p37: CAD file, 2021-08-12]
400x400/Panels/Back.Electronics.Panel.STEP
556.8 x 540.7 x 3.17 mm

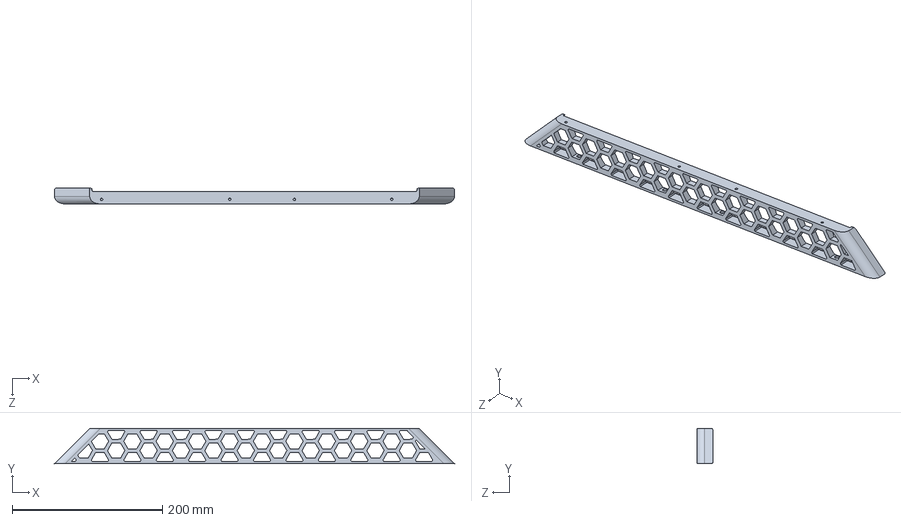
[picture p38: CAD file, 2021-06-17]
400x400/Sides-HoneyComb/Back-Hcomb-Right.STEP
531.7 x 46.8 x 21.0 mm

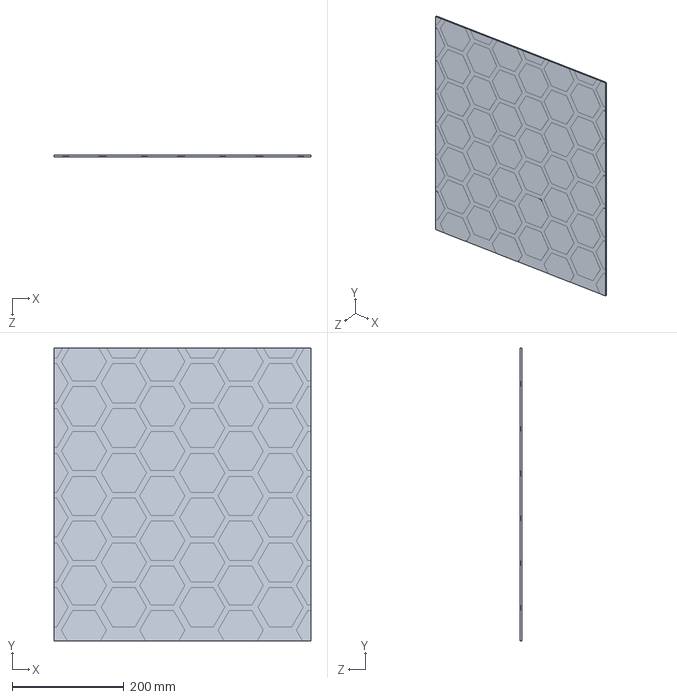
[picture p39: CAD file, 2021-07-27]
400x400/TOP-LID/Plexi-Top-Cover.Engraved.STEP
458.5 x 523.5 x 3.17 mm

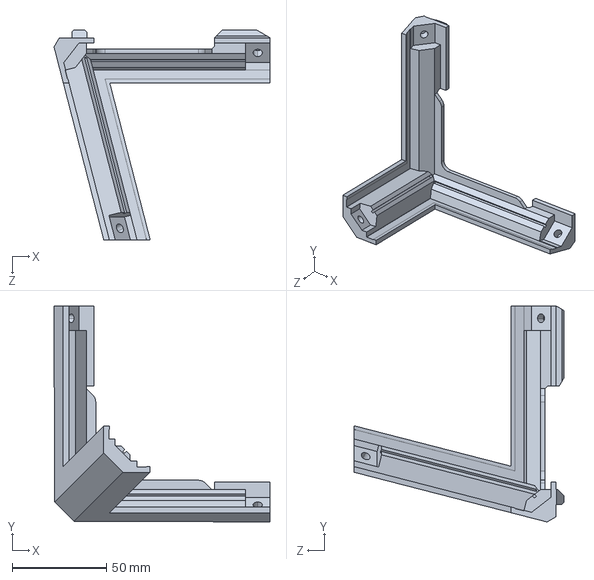
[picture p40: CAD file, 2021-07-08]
400x400/TOP-LID/STEP-FILES/Btm-Back-RIGHT-Corner.V6.20mm.STEP
114.6 x 114.6 x 111.2 mm

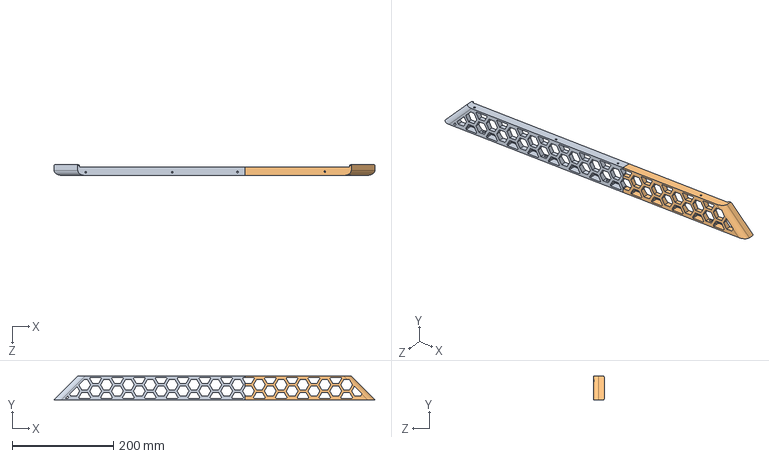
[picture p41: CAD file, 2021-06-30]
500x500/HCOMB-SIDES/hcomb-RIGHT.500mm.STEP
632.7 x 46.8 x 21.0 mm

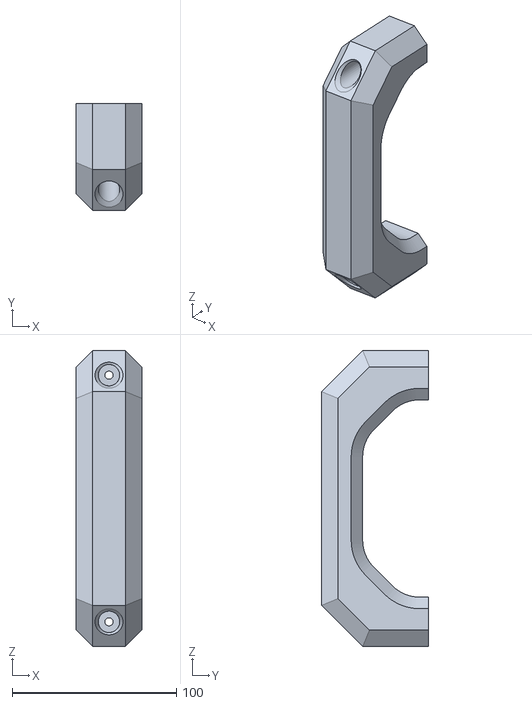
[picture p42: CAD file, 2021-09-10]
500x500/MARCEL-Remix-MODS/Panels/Handle.stl
40.0 x 65.0 x 180.0

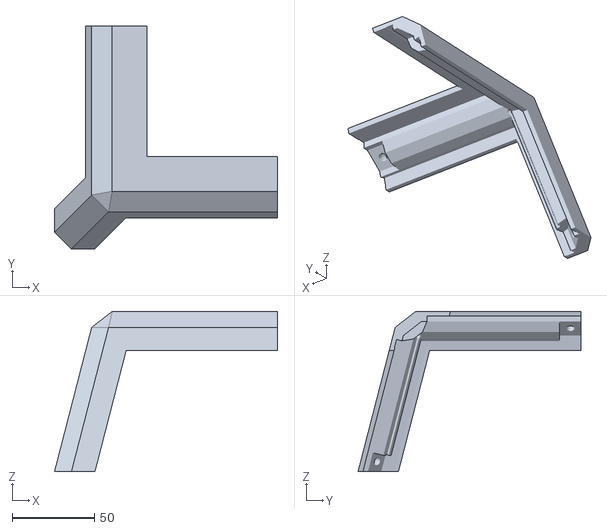
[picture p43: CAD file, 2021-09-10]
500x500/MARCEL-Remix-MODS/Top-Lid/500_Top_Corner.stl
135.8 x 135.8 x 97.5

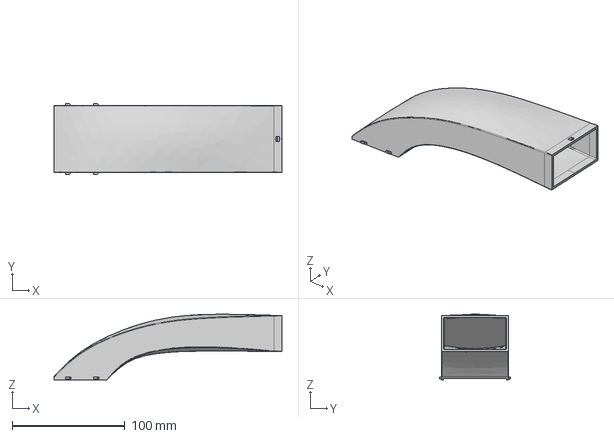
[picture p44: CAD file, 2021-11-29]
Activated-Carbon-Filter/300mm/CF-Filter Duct short.step
201.8 x 62.7 x 58.2 mm

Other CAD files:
Activated-Carbon-Filter/Air-Duct-Internal.STEP
CAN_Bus/Cable-Holder-V4.STEP.STL
LCD-MOUNT/BTT-Pi-TFT-CASE-Back.STEP
Misc/120-mount-3030.STEP
300x300/HCOMB-SIDES/HCOMB-LEFT.300mm.STL
300x300/HCOMB-SIDES/HCOMB-RIGHT.300mm.STEP
300x300/HCOMB-SIDES/HCOMB-RIGHT.300mm.STL
400x400/ADXL-Mount.STL
400x400/Clip-MidPoint-3mm-3030.STL
400x400/Door-Hinge-LEFT.STL
400x400/Door-Hinge-Plate.STL
400x400/Door-Hinge-Right.STEP
400x400/Door-Hinge-Right.STL
400x400/HCOMB-Russel-Remix/Back-Hcomb-Left-Half2-IEC.step
400x400/HCOMB-Russel-Remix/Back-Hcomb-Left-Half2-IEC.stl
400x400/HCOMB-Russel-Remix/Back-Hcomb-Left-Half2-RJ45.stl
400x400/Hinge-Front-Doors.STEP
400x400/Hinge-Front-Doors.STL
400x400/LED-Clip.100mm.NeoPixel.STL
400x400/LED-Clip.100mm.neopixel.STEP
400x400/LED.CLIP.V2.STL
400x400/Panels/BACK-Electronics-Top-Cover.STEP
400x400/Panels/BACK-Electronics-Top-Cover.STL
400x400/Panels/BTM-Panel-V2.STL
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

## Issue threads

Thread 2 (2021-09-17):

fitting psu side panel with an electronics panel

tonywright, 2021-09-17:
I don't have my v-core 3 yet but will the 300mm psu side panels fit when you have a 4mm electronics panel fitted? The gap between the frames is 47mm minus the 4mm panel leaves 43mm, the psu panels are 47mm wide.

Hope this is the correct place to post this.

cyborgcnc, 2021-09-17:
Hi,

The honeycomb PSU side panels, do not fit on top of the electronics
panel..they fit beside it, so it does not matter how thick the panel is.
IT DOES matter how long/dimensions of the electronics panel is....See the
picture below, it is a TOP view of where the electronics panel, and the
side HB pattern fit....makes sense?

[image: image.png]

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

tonywright, 2021-09-17:
That makes total sense, thanks for clarifying. In the construction images it looks like the panel fits 100% the width of the panel frame and that the panel frame sits right up to the edge of the printer frame.
I guess I can finish printing the parts for when my printer does arrive :)

Closed 2021-09-17.

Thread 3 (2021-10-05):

300mm lid remix missing bottom bar STLs

ChewyJetpack, 2021-10-05:
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

See above list of STLs from the zip file.

The side bars are there; 'Btm-Bar-SIDES.HALF 4no.stl', but no front/back bars included.

ChewyJetpack, 2021-10-05:
I don't have Facebook so I can't get in touch with Phil there, but it would be massively appreciated if he could update the zip file - I've printed all the other parts.

ChewyJetpack, 2021-10-06:
[Lid_Bottom_Center_v2_300x300.stl.zip](https://github.com/cyborgcnc/CYBORGCNC__RRVC3MOD/files/7296348/Lid_Bottom_Center_v2_300x300.stl.zip)
Here is the missing stl provided by @RPK3D on the RR discord.

Closed 2021-11-19.

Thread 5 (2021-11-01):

WobbleRings Back BOM

NightLink42, 2021-11-01:
The original screws used to attach the back arm to the rail are not long enough. BOM needs to include x4 35mm m3 bolts

cyborgcnc, 2021-11-01:
Thanks for the feedback!

Spiro

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

Closed 2021-11-01.

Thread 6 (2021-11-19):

Assembly of the complete ratrig

Enric2000, 2021-11-19:
Hi it's possible to have the complete step file with all the assembly and the printer?

cyborgcnc, 2021-11-19:
The ratrig CAD files are all available from their OnShape pape, and you can download the entire assembly there, including all other files in many formats.

Closed 2021-11-19.

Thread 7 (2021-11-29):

Contrib: 300mm version of Carbon Filter fan duct

jbjhjm, 2021-11-29:
I rebuilt the Carbon Filter fan duct to fit for a 300mm V-Core 3.
No time to open a PR but I thought you may want to add it.
Zip contains step and stl.

[Activated-Carbon-Filter.zip](https://github.com/cyborgcnc/CYBORGCNC__RRVC3MOD/files/7618440/Activated-Carbon-Filter.zip)

cyborgcnc, 2021-11-29:
Thank you Jannik!!

I will post this to the Github repository, and make sure I mention you in
the credits!

GOOD WORK!

Spiro

On Mon, Nov 29, 2021 at 8:32 AM Jannik Mewes ***@***.***>
wrote:

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

Closed 2021-11-29.

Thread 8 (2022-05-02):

3d model of can bus SHT42?

ManuelPeiro, 2022-05-02:
Hi,

where i can find de 3d model of the board?

thx

cyborgcnc, 2022-05-02:
It is on mellow github...

https://github.com/Mellow-3D/Klipper-CAN-Toolboards

On Mon, May 2, 2022 at 12:49 AM ManuelPeiro ***@***.***>
wrote:

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

Closed 2022-06-15.

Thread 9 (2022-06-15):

Often error... and work stop

ManuelPeiro, 2022-06-15:
Hi.

After a while using the SHT 42 board... I have to say that it is an upgrade that I consider INDISPENSABLE.
It changes a lot from carrying a bundle of approximately 10 cables, to carrying only 3...
Now, not everything is perfect. The problem that I find is that very often, more than expected, the printing fails due to lack of communication between the SHT and the main board, giving me this error.."MC 'extruder' reports error: GSTAT: 00000001 reset=1( Reset)"...

I have connected the SHT via USB to the Rpi... I have tried different USBs cables, in case it was that, and so far nothing.

If I used the UTOC board,do you think would this be solved?
Or other idea apreciated

ManuelPeiro, 2022-06-15:
only Mellow models UTOC 1 and 3 are suitable for tool board? or can use another?

Closed 2022-06-15.

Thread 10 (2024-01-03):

F360 File for remix

Apulo, 2024-01-03:
Would it be possible to get the source files (F360 or other) so I can remix the left panel a bit to add an additional inlet and switch? I'm going to add separate AC input for my bed heater since it's such high wattage.

Cheers! Love the design.
